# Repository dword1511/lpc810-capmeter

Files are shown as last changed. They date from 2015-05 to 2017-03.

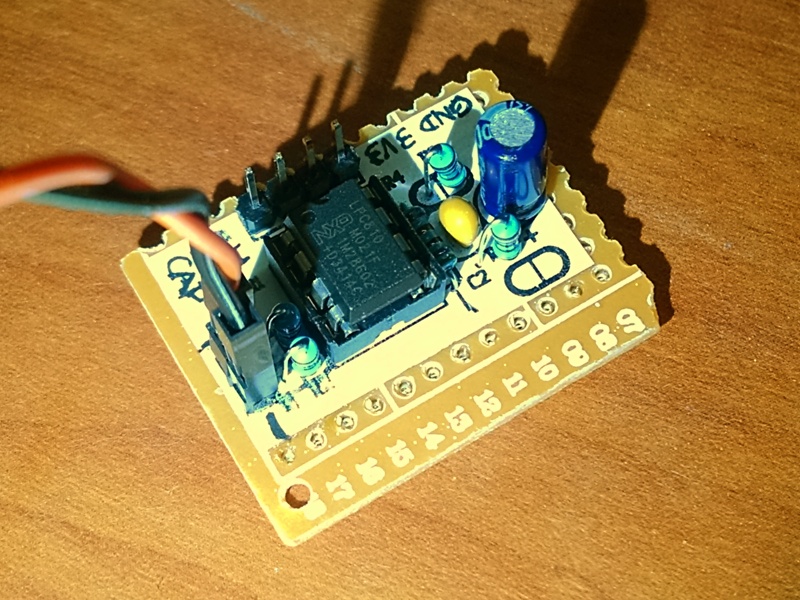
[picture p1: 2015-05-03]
hw-proto/photo.jpg

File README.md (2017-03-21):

LPC810-based Capacitance Meter
==============================

Pros:

* Dual-speed measurement
* Auto-ranging
* 1pF to 9999.99uF
* Reasonable precision after stray capacitance subtracted
* Calibration-free for C > 1nF if precision resistors used
* UART output (115200 8N1)
* Compact
* Affordable
* Single-chip, low component count
* SMD-free, prototype-board-friendly layout
* Only uses common components
* Microcontroller can be flashed via UART

Cons:

* May get affected by ESR and leakage
* Measuring frequency not controllable
* 1% error in clock introduced by the microcontroller
* Require relatively new arm-none-eabi toolchain for reasonable binary size
* Time-constant-based approach is not as precise as LCR bridge
* Requires 3.3V power supply

Refs:

* [Capacitance Meter and RC Time Constants](http://www.arduino.cc/en/Tutorial/CapacitanceMeter)
* [Getting Started with the LPC810](https://learn.adafruit.com/getting-started-with-the-lpc810/introduction)
* [LPC810 CodeBase](https://github.com/microbuilder/LPC810_CodeBase)
* [lpc21isp](http://sourceforge.net/projects/lpc21isp/)
* [GNU Tools for ARM Embedded Processors](https://launchpad.net/gcc-arm-embedded) **(If code size is too big, try this toolchain)**
* [LPCXpresso Sample Code Bundle for the LPC8xx](http://www.lpcware.com/content/nxpfile/lpcxpresso-sample-code-bundle-lpc8xx)
* [NXP Switch Matrix Tool for LPC81x](http://www.lpcware.com/content/nxpfile/nxp-switch-matrix-tool-lpc800)
* [A smarter way to write micros()](http://micromouseusa.com/?p=296)

Compiling:
    cd src && make && make flash
Use `CROSS=/path/to/toolchain-` and `COMPORT=/dev/ttyACM0` to change toolchain / serial used for flashing.

[OSH Park](https://oshpark.com/shared_projects/58C6wB6e)

Pin Assignment:

         +---v---+
    TXD -|1     8|- VREF
    RXD -|2     7|- GND
    IO3 -|3     6|- 3V3
    IO2 -|4     5|- VCAP
         +-------+

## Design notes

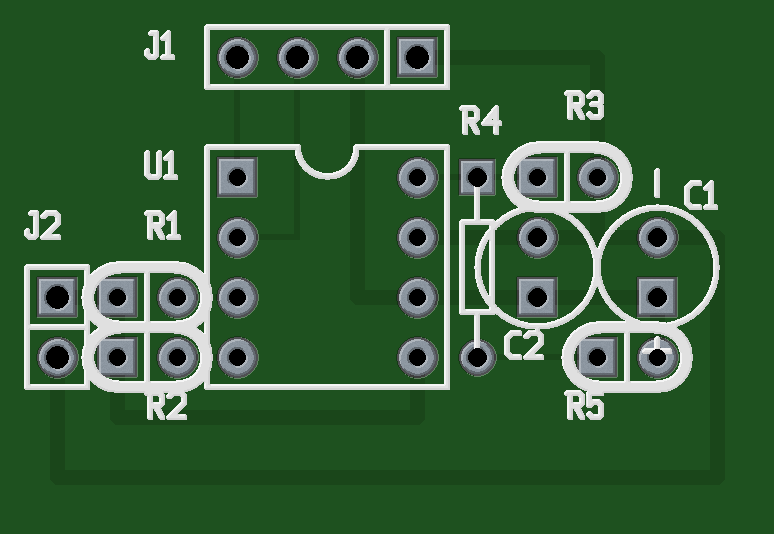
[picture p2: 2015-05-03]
hw-proto/pcb.png

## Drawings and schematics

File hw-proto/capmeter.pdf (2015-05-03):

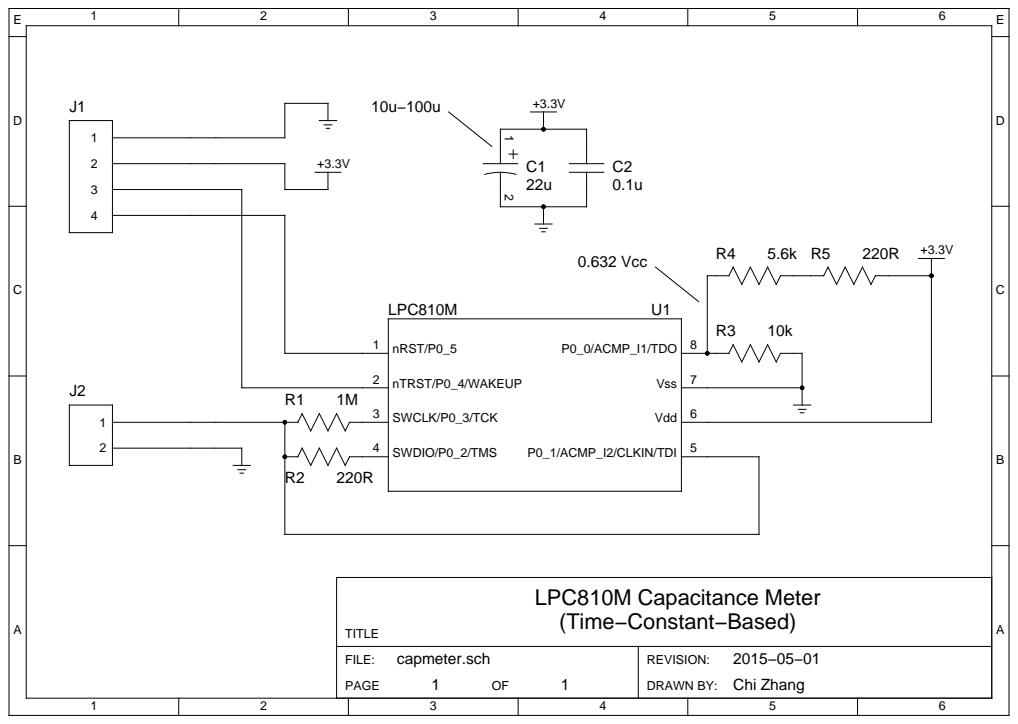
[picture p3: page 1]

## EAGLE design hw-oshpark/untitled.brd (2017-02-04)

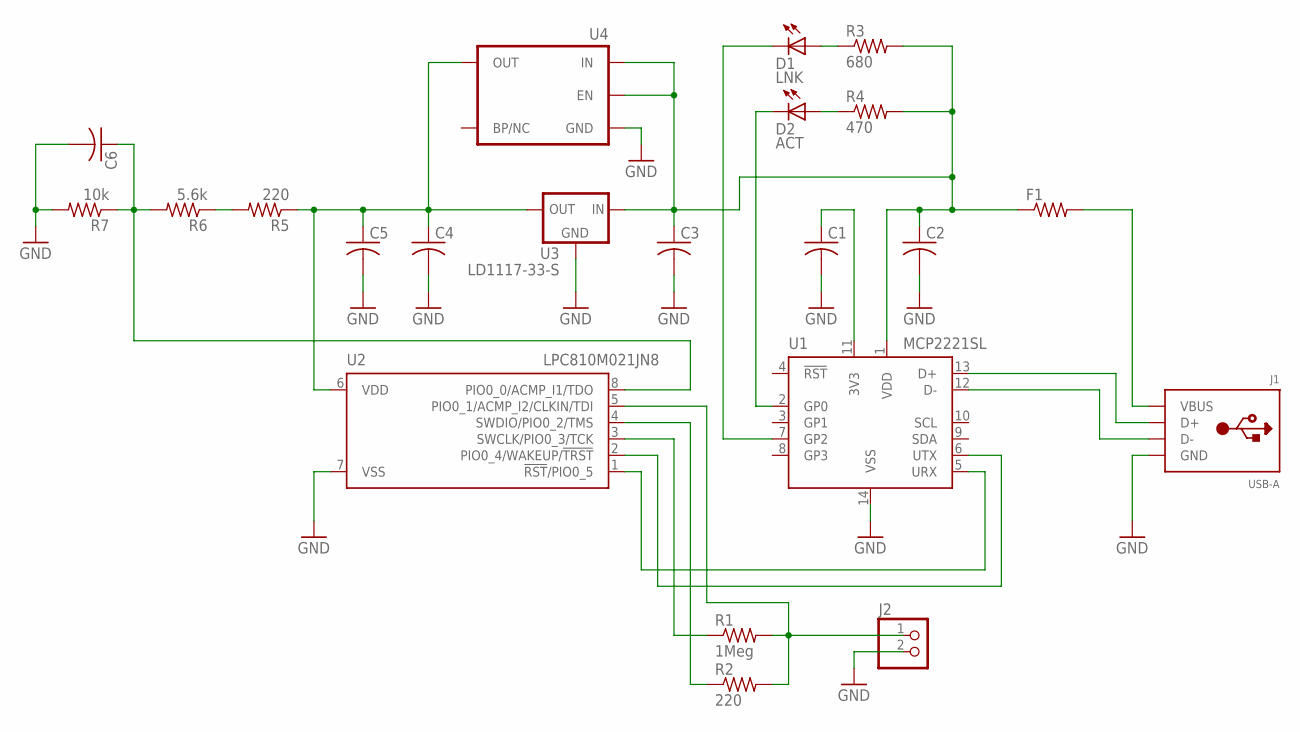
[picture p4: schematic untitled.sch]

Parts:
C1, C2, C3, C4, C5, C6: C-USC0805; C0805
D1: LNK; SML0805
D2: ACT; SML0805
F1: R-US_R0805; R0805
J1: USB-A; MOLEX_480371000
J2: PINHD-1X2; 1X02
R1: 1Meg; R0805
R2, R5: 220; R0805
R3: 680; R0805
R4: 470; R0805
R6: 5.6k; R0805
R7: 10k; R0805
U1: MCP2221SL; SOIC-14
U2: LPC810M021JN8; DIP-8
U3: LD1117-33-S; SOT-223
U4: LDO-SOT23-5; SOT-23-5

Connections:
GND: C1.2, C2.2, C3.2, C4.2, C5.2, C6.2, J1.4 (GND), J2.2, R7.2, U1.14 (VSS), U2.7 (VSS), U3.1 (GND), U4.2 (GND)
unnamed: F1.2, J1.1 (VBUS)
unnamed: D2.C, U1.2 (GP0)
unnamed: C1.1, U1.11 (3V3)
unnamed: J1.3 (D+), U1.13 (D+)
unnamed: J1.2 (D-), U1.12 (D-)
unnamed: U1.5 (URX), U2.1 (!RST!/PIO0_5)
unnamed: U1.6 (UTX), U2.2 (PIO0_4/WAKEUP/!TRST!)
unnamed: R1.1, U2.3 (SWCLK/PIO0_3/TCK)
unnamed: R2.1, U2.4 (SWDIO/PIO0_2/TMS)
unnamed: J2.1, R1.2, R2.2, U2.5 (PIO0_1/ACMP_I2/CLKIN/TDI)
unnamed: D1.C, U1.7 (GP2)
unnamed: D2.A, R4.1
unnamed: D1.A, R3.1
unnamed: C6.1, R6.2, R7.1, U2.8 (PIO0_0/ACMP_I1/TDO)
unnamed: R5.2, R6.1
unnamed: C2.1, C3.1, F1.1, R3.2, R4.2, U1.1 (VDD), U3.3 (IN), U4.1 (IN), U4.3 (EN)
OUT: C4.1, C5.1, R5.1, U2.6 (VDD), U3.2 (OUT), U3.4 (OUT), U4.5 (OUT)

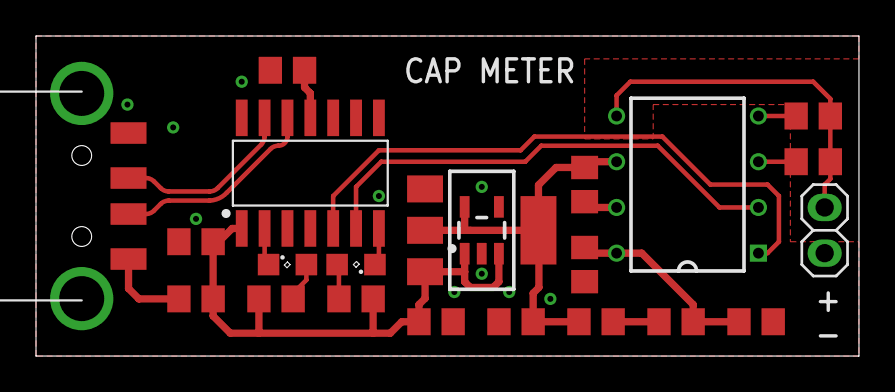
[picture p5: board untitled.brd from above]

Board: 2 copper layers, 45.7 x 17.8 mm, 22 parts (0 on the bottom side), 18 nets.

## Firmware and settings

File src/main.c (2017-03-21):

#include <stdio.h>
#include <stdbool.h>
#include <lpc8xx.h>

#include "acmp.h"
#include "uart.h"

#define _BV(x)       (1 << x)
#define UNLIKELY(e)  (__builtin_expect(!!(e), false))

#define GPIO_ACMP_I1 0
#define GPIO_ACMP_I2 1
#define GPIO_R220    2
#define GPIO_R1M     3

#define ACMPIN_REF   ACMPIN_I1
#define ACMPIN_CAP   ACMPIN_I2

#define INTERVAL_MS  200
#define BAUDRATE     115200

#define CYCLE_PER_US (__SYSTEM_CLOCK/1000000)
#define CYCLE_PER_MS (__SYSTEM_CLOCK/1000)
#define GPIO_FLOAT   (~(3 << 3))

// 200ms / 1M = 200nF (fast-mode kicks-in for C > 200nF)
// 200nF * 220R = 44us
// 200ms / 44us = 4546 measurements = 1M/220 (magic! stupid me)
#define RES_FRATIO   (1000000/220 + 1)
#define SAMPLES_MAX  RES_FRATIO

/*
 * NOTE: every clock is ~33ns. Voltage input hooked up to ACMP_I2.
 * For 1pF resolution, need 1Mohm resistor and 1us resolution.
 * 1us timer with uint32_t warps every 1.2 hours.
 * 24-bit systick register warps every 24ms.
 * uint32_t cannot cover 5pF all the way up to 4700uF.
 * So use uint64_t. (or have a separate mF instead)
 *
 * SysTick INT: count ms for delay functions. needs highest priority.
 * Main Loop: take and record measurement and resets the circuit.
 *            check timestamp and report results every INTERVAL_MS ms.
 */

/*
 * NOTE: system performance:
 * 18-20pF minimum (due to stray capacitance, can be calibrated. ~12pF on PCB, 7pF on test leads)
 * 5Hz data output (for C's that are not too large)
 * Sensitive to resistance (ESR & leakage)
 * 1pf takes 1us. switches to fast mode at 200nF. minimum measurement in fastmode takes 44us.
 */

// TODO: Recv cmd from UART
// H = hold (just new line)
// Z = set distributed capacitors
// L = leakage assessment

volatile static uint32_t systime_ms = 0;

void SysTick_Handler(void) {
  // Keep it as short as possible, to reduce error.
  systime_ms ++;
}

static inline uint32_t capmeter_timer_get_us(void) {
  return systime_ms * 1000 + 1000 - (SysTick->VAL / CYCLE_PER_US);
}

void capmeter_timer_init(void) {
  // SysTick Millisecond Timer
  while ((SysTick_Config(CYCLE_PER_MS)) != 0); // 1ms interval
  NVIC_SetPriority(SysTick_IRQn, 0);           // highest priority
}

void capmeter_delay(uint32_t ms) {
  ms += systime_ms;
  while(systime_ms < ms);
}

void capmeter_swm_init(void) {
  // Enable SWM
  LPC_SYSCON->SYSAHBCLKCTRL |= (1<<7);

  // Enable UART
  LPC_SWM->PINASSIGN0 = 0xffff0405UL;

  // Enable ACMP
  LPC_SWM->PINENABLE0 = 0xfffffffcUL;

  // ACMP PINs IN, All PINs FLOAT
  LPC_GPIO_PORT->CLR0 = (_BV(GPIO_ACMP_I1) | _BV(GPIO_ACMP_I2) | _BV(GPIO_R220) | _BV(GPIO_R1M));
  LPC_IOCON->PIO0_2  &= GPIO_FLOAT;
  LPC_IOCON->PIO0_3  &= GPIO_FLOAT;
  LPC_GPIO_PORT->DIR0 = (_BV(GPIO_R220) | _BV(GPIO_R1M));
}

void capmeter_discharge(void) {
  // Setup comparator for monitoring the discharge.
  // Do not just wait, 220R * 4700uF > 1s
  // You can get another sample while discharging, but currently not doing this,
  // especially where LPC810's sink only provides 4mA before rising to 0.4V...
  acmp_set_input(ACMPIN_CAP, ACMPIN_GND); // If this does not work, we will have to use the voltage ladder for a small offset

  // All PINs LOW
  LPC_GPIO_PORT->DIR0 = (_BV(GPIO_R220) | _BV(GPIO_R1M));
  LPC_GPIO_PORT->CLR0 = (_BV(GPIO_R220) | _BV(GPIO_R1M));

  while (ACMP_OUT);
}

uint64_t capmeter_charge(bool fast) {
  uint64_t us_start, us_stop;
  uint32_t last_ms = systime_ms;

  // Setup comparator
  acmp_set_input(ACMPIN_REF, ACMPIN_CAP);

  // GPIO High (to be specific, hold low, configure direction, then pull the correct pin high)
  LPC_GPIO_PORT->DIR0 = fast ? _BV(GPIO_R220) : _BV(GPIO_R1M);
  LPC_GPIO_PORT->SET0 = (_BV(GPIO_R220) | _BV(GPIO_R1M));

  // Take time snapshot
  us_start = capmeter_timer_get_us();

  // wait comparator. use identical operations to minimize error.
  while (ACMP_OUT) {
    if (UNLIKELY(!fast && ((systime_ms - last_ms) > INTERVAL_MS))) {
      return 0;
    }
  }
  us_stop = capmeter_timer_get_us();

  // Calculate diff, convert to pF (*4546UL in fast)
  // TODO: what will happen when time warps? 0xffffffffffffffffUL
  if (fast) {
    return (us_stop - us_start) * RES_FRATIO;
  } else {
    return (us_stop - us_start);
  }
}

#define MESSAGE_LEN 14
static const char* msg_2big = " E           \r";
static bool blink = false;

// TODO: pass calibration, output '-' sign & 0 if <0
void capmeter_send_data(uint64_t pf, bool fast) {
  char msg[MESSAGE_LEN];
  char unit = 'p';
  uint32_t remainder = 0;
  bool leading = true;

  if (pf > 9999999999UL) {
    uart0Send(msg_2big, MESSAGE_LEN);
    return;
  }

  if (pf > 1000000UL) {
    unit = 'u';
    remainder = pf % 1000000UL;
    remainder /= 1000UL;
    pf /= 1000000UL;
  } else if (pf > 1000UL) {
    unit = 'n';
    remainder = pf % 1000UL;
    pf /= 1000UL;
  }

  if (pf >= 1000UL) {
    msg[0] = (pf / 1000UL) + 0x30;
    leading = false;
  } else {
    msg[0] = ' ';
  }

  pf %= 1000UL;
  if ((pf >= 100UL) || (!leading)) {
    msg[1] = (pf / 100UL) + 0x30;
    leading = false;
  } else {
    msg[1] = ' ';
  }

  pf %= 100UL;
  if ((pf >= 10UL) || (!leading)) {
    msg[2] = (pf / 10UL) + 0x30;
  } else {
    msg[2] = ' ';
  }

  pf %= 10UL;
  msg[3] = pf + 0x30;

  msg[4] = '.';

  msg[5] = (remainder / 100UL) + 0x30;
  remainder %= 100UL;
  msg[6] = (remainder / 10UL) + 0x30;

  msg[7] = ' ';
  msg[8] = unit;
  msg[9] = 'F';

  msg[10] = ' ';
  if (fast) {
    msg[11] = 'L';
  } else {
    msg[11] = ' ';
  }

  if (blink) {
    msg[12] = '.';
  } else {
    msg[12] = ' ';
  }
  blink = !blink;

  msg[13] = '\r';
  uart0Send(msg, MESSAGE_LEN);
}

int main(void) {
  capmeter_swm_init();
  uart0Init(BAUDRATE);
  capmeter_timer_init();
  acmp_init();

  uint32_t last_report_ms = 0;
  bool     fast           = false; // gets enabled automatically to measure big capacitors with 220R resistor
  uint64_t sum            = 0UL;
  uint32_t samples        = 0;

  while(true) {
    sum += capmeter_charge(fast);
    samples ++;
    capmeter_discharge();

    // Handle systime_ms wrapping but not too carefully, it is rare
    if ((systime_ms - last_report_ms > INTERVAL_MS) || (last_report_ms > systime_ms)) {
      last_report_ms = systime_ms;
      capmeter_send_data(sum / samples, fast);

      if (samples == 1) {
        fast = true;
      }
      if (samples > SAMPLES_MAX) {
        fast = false;
      }
      sum = 0UL;
      samples = 0;
    }
  }
}

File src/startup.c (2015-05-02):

#if defined (__USE_CMSIS)
#include <lpc8xx.h>
#endif

extern int main(void);

// Allocated stack space
#define STACKSIZE 64

static unsigned int StackMem[STACKSIZE];
#define _pStackTop ((void *)((unsigned int)StackMem + sizeof(StackMem)))

//*****************************************************************************

#define ALIAS(f) __attribute__ ((weak, alias (#f)))

//*****************************************************************************
//
// Forward declaration of the default handlers. These are aliased.
// When the application defines a handler (with the same name), this will
// automatically take precedence over these weak definitions
//
//*****************************************************************************

void ResetISR(void);
void IntDefaultHandler(void);

void NMI_Handler(void)        ALIAS(IntDefaultHandler);
void HardFault_Handler(void)  ALIAS(IntDefaultHandler);
void SVC_Handler(void)        ALIAS(IntDefaultHandler);
void PendSV_Handler(void)     ALIAS(IntDefaultHandler);
void SysTick_Handler(void)    ALIAS(IntDefaultHandler);

//*****************************************************************************
//
// Forward declaration of the specific IRQ handlers. These are aliased
// to the IntDefaultHandler, which is a 'forever' loop. When the application
// defines a handler (with the same name), this will automatically take
// precedence over these weak definitions
//
//*****************************************************************************
void SPI0_IRQHandler(void)    ALIAS(IntDefaultHandler);
void SPI1_IRQHandler(void)    ALIAS(IntDefaultHandler);
void UART0_IRQHandler(void)   ALIAS(IntDefaultHandler);
void UART1_IRQHandler(void)   ALIAS(IntDefaultHandler);
void UART2_IRQHandler(void)   ALIAS(IntDefaultHandler);
void I2C_IRQHandler(void)     ALIAS(IntDefaultHandler);
void SCT_IRQHandler(void)     ALIAS(IntDefaultHandler);
void MRT_IRQHandler(void)     ALIAS(IntDefaultHandler);
void CMP_IRQHandler(void)     ALIAS(IntDefaultHandler);
void WDT_IRQHandler(void)     ALIAS(IntDefaultHandler);
void BOD_IRQHandler(void)     ALIAS(IntDefaultHandler);
void WKT_IRQHandler(void)     ALIAS(IntDefaultHandler);
void PININT0_IRQHandler(void) ALIAS(IntDefaultHandler);
void PININT1_IRQHandler(void) ALIAS(IntDefaultHandler);
void PININT2_IRQHandler(void) ALIAS(IntDefaultHandler);
void PININT3_IRQHandler(void) ALIAS(IntDefaultHandler);
void PININT4_IRQHandler(void) ALIAS(IntDefaultHandler);
void PININT5_IRQHandler(void) ALIAS(IntDefaultHandler);
void PININT6_IRQHandler(void) ALIAS(IntDefaultHandler);
void PININT7_IRQHandler(void) ALIAS(IntDefaultHandler);

//*****************************************************************************
//
// The vector table.
// This relies on the linker script to place at correct location in memory.
//
//*****************************************************************************
extern void (* const g_pfnVectors[])(void);
__attribute__ ((section(".isr_vector")))
void (* const g_pfnVectors[])(void) = {
  // Core Level - CM0plus
  _pStackTop,           // The initial stack pointer
  ResetISR,             // The reset handler
  NMI_Handler,          // The NMI handler
  HardFault_Handler,    // The hard fault handler
  0,                    // Reserved
  0,                    // Reserved
  0,                    // Reserved
  0,                    // Reserved
  0,                    // Reserved
  0,                    // Reserved
  0,                    // Reserved
  SVC_Handler,          // SVCall handler
  0,                    // Reserved
  0,                    // Reserved
  PendSV_Handler,       // The PendSV handler
  SysTick_Handler,      // The SysTick handler

  // Chip Level - LPC8xx
  SPI0_IRQHandler,      // SPI0 controller
  SPI1_IRQHandler,      // SPI1 controller
  0,                    // Reserved
  UART0_IRQHandler,     // UART0
  UART1_IRQHandler,     // UART1
  UART2_IRQHandler,     // UART2
  0,                    // Reserved
  0,                    // Reserved
  I2C_IRQHandler,       // I2C controller
  SCT_IRQHandler,       // Smart Counter Timer
  MRT_IRQHandler,       // Multi-Rate Timer
  CMP_IRQHandler,       // Comparator
  WDT_IRQHandler,       // PIO1 (0:11)
  BOD_IRQHandler,       // Brown Out Detect
  0,                    // Reserved
  WKT_IRQHandler,       // Wakeup timer
  0,                    // Reserved
  0,                    // Reserved
  0,                    // Reserved
  0,                    // Reserved
  0,                    // Reserved
  0,                    // Reserved
  0,                    // Reserved
  0,                    // Reserved
  PININT0_IRQHandler,   // PIO INT0
  PININT1_IRQHandler,   // PIO INT1
  PININT2_IRQHandler,   // PIO INT2
  PININT3_IRQHandler,   // PIO INT3
  PININT4_IRQHandler,   // PIO INT4
  PININT5_IRQHandler,   // PIO INT5
  PININT6_IRQHandler,   // PIO INT6
  PININT7_IRQHandler,   // PIO INT7

}; /* End of g_pfnVectors */


//*****************************************************************************
// Reset entry point for your code.
// Sets up a simple C runtime environment.
//*****************************************************************************

extern unsigned int _etext;
extern unsigned int _data;
extern unsigned int _edata;
extern unsigned int _bss;
extern unsigned int _ebss;

// Simple gcc-compatible C runtime init
static inline void crt0(void) {
  unsigned int *src, *dest, *dend;

  // copy the data section
  src  = (unsigned int *)(&_etext);
  dest = (unsigned int *)(&_data);
  dend = (unsigned int *)(&_edata);
  while (dest < dend) *(dest++) = *(src++);

  // blank the bss section
  dest = (unsigned int *)(&_bss);
  dend = (unsigned int *)(&_ebss);
  while (dest < dend) *(dest++) = 0;
}

__attribute__ ((section(".after_vectors")))
void ResetISR(void) {
#ifdef __USE_CMSIS
  SystemInit();
#endif
  crt0();
  main();
  while (1); // hang if main returns
}

//*****************************************************************************
//
// Processor ends up here if an unexpected interrupt / exception occurs or a
// specific handler is not present in the application code.
//
//Override the ones here by defining your own
// handler routines in your application code.
//
//*****************************************************************************
__attribute__ ((section(".after_vectors")))
void IntDefaultHandler(void) {
  while(1);
}

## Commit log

2015-05-03 revise pcb
    [capmeter.sch]
2017-02-04 eagle design file (slightly newer than oshpark version)
    [untitled.brd, untitled.sch]
2017-03-21 move old hw to hw-proto
    [capmeter.sch]
